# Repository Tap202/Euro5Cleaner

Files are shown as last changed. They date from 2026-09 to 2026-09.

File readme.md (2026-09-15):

# 🏍️ Yamaha MT-09 SP (Euro 5 / Euro 5+) CAN Bus Tool & Cockpit Suite







An autonomous, production-grade CAN bus diagnostic tool, real-time telemetry cockpit, and exhaust fault cleaner tailored for the **2021–2026+ Yamaha MT-09 / MT-09 SP (Euro 5 / Euro 5+ / CP3)** running on an ultra-compact **ESP32-C3 Super Mini Plus**.

Designed to live permanently under the passenger seat, it eliminates exhaust Check Engine Lights (CEL), decodes Yamaha ECU diagnostic trouble codes in real-time, logs clear history to persistent NVS flash memory, and pairs instantly with your smartphone over Bluetooth Low Energy (BLE)—with zero battery drain when parked.

---

## ⚡ Key Highlights

* 🛡️ **100% Autonomous Headless Auto-Clear**:
  * Operates completely silently in the background—**zero user interaction or phone connection required**.
  * Automatically scans ECU for trouble codes 4 seconds after ignition key-ON and clears exhaust / O2 faults (e.g. `P0036`, `P0030`) caused by aftermarket exhausts (Akrapovič, Arrow, decat headers).
  * Automatically detects engine shutdown and runs a background scan/clear cycle 3 seconds later.
* 💾 **Persistent Flash NVS Clear Logger**:
  * Automatically records every clear event to ESP32 Flash memory (`Preferences` NVS).
  * Logs boot count, uptime seconds, trigger source (`BOOT_AUTO`, `POST_RIDE`, `BLE_MANUAL`), codes cleared, and execution status.
  * Survives battery disconnections and reboots; retrievable at any time over BLE or Serial CLI.
* 🔒 **Hardware-Enforced Engine-OFF Safety Interlock**:
  * Mode 04 clear frames are strictly locked out whenever the engine is running or RPM > 0.
* 📱 **Bluetooth Low Energy (BLE 5.0) GATT Interface**:
  * Connects directly to smartphones with zero Wi-Fi network switching or internet interruption.
  * Hosted live on **GitHub Pages** (no file download needed): [**https://tap202.github.io/Euro5Cleaner/**](https://tap202.github.io/Euro5Cleaner/).
  * Works on **iOS (iPhone/iPad)** via **Bluefy** or **nRF Connect**, and on **Android/PC/Mac** via **Google Chrome** or **Edge**.
* 🌙 **Ultra-Low Power Deep Sleep (< 15 µA)**:
  * Automatically enters deep sleep after 60 seconds of CAN silence and BLE disconnection.
  * Instant hardware wakeup via GPIO 3 (`CAN_RX`) on the first dominant start-of-frame bit when the ignition key is turned ON.
  * Safe for months of parking without draining the motorcycle battery.

---

## 📱 Mobile BLE Cockpit & iOS Access Guide

### 🌐 Hosted Online via GitHub Pages (Zero Downloads Required)

You do **not** need to manually download or transfer HTML files to your phone. The BLE Cockpit is hosted for free on GitHub Pages over secure HTTPS:

👉 [**https://tap202.github.io/Euro5Cleaner/**](https://tap202.github.io/Euro5Cleaner/)

---

### 🍏 Accessing on iOS (iPhone / iPad)

> [!IMPORTANT]
> **Why Safari doesn't connect:** Apple's WebKit engine in standard Safari and Chrome for iOS intentionally does **not** support the Web Bluetooth API (`navigator.bluetooth`). 

You have two simple, free ways to use it on iOS:

#### Option A: Free Web BLE Browser (Recommended — Full Visual Dashboard)
1. Install **[Bluefy – Web BLE Browser](https://apps.apple.com/app/bluefy-web-ble-browser/id1492822055)** (Free on the iOS App Store).
2. Open Bluefy and navigate to:
   ```
   https://tap202.github.io/Euro5Cleaner/
   ```
3. Tap **Connect BLE** $\to$ select **`MT09-Cleaner`**.
4. *(Optional)* Tap the **Share / Action** icon in Bluefy and choose **"Add to Home Screen"** to turn it into a full-screen, standalone app on your iPhone!

#### Option B: Generic BLE GATT App (nRF Connect)
1. Install **[nRF Connect for Mobile](https://apps.apple.com/app/nrf-connect-for-mobile/id1054362403)** (Free on the iOS App Store).
2. Scan and connect to **`MT09-Cleaner`** (Service UUID `000018F0-0000-1000-8000-00805F9B34FB`).
3. Tap the Download / Notify icon on:
   * **`18F1` (Status)**: Live JSON string with ECU state and engine status.
   * **`18F2` (DTCs)**: Live trouble codes and descriptions.
   * **`18F4` (Logs)**: NVS flash clear history entries.
4. Write UTF-8 text commands to **`18F3` (Command)**:
   * `SCAN` : Query ECU for confirmed & pending trouble codes.
   * `CLEAR`: Safely clear codes and reset Check Engine Light.
   * `LOGS` : Refresh stored NVS history.
   * `ERASE_LOGS`: Wipe flash history.

---

### 🤖 Accessing on Android, Windows, Mac & Linux

Simply open [**https://tap202.github.io/Euro5Cleaner/**](https://tap202.github.io/Euro5Cleaner/) directly in **Google Chrome** or **Microsoft Edge**:
1. Click **Connect BLE** $\to$ select **`MT09-Cleaner`** in the pairing dialog.
2. The cockpit will automatically subscribe to notifications and display real-time statuses and logs.

---

## 🔌 Hardware Setup & Pinout

### 1. ESP32-C3 Super Mini to 3.3V CAN Transceiver (SN65HVD230)

> [!IMPORTANT]
> Always use a **3.3V CAN transceiver** such as the **SN65HVD230** or **VP230**. Do **not** connect a 5V transceiver (e.g. MCP2551 / TJA1050) directly to the ESP32 GPIOs without logic level shifters.

| ESP32-C3 Super Mini Pin | SN65HVD230 Transceiver | Description |
| :--- | :--- | :--- |
| `3V3` | `3V3` (VCC) | 3.3V Logic Supply |
| `GND` | `GND` | System Ground |
| `GPIO 21` | `TX` / `TXD` | TWAI / CAN Transmit |
| `GPIO 3` | `RX` / `RXD` | TWAI / CAN Receive (RTC GPIO Wakeup Pin) |
| `GPIO 8` | *(Onboard LED)* | Active-LOW CAN packet activity indicator |

---

### 2. Yamaha Euro 5 Diagnostic Connector (ISO 19689 Red 6-Pin)

Located underneath the passenger seat of 2021+ Yamaha MT-09 / MT-09 SP models:

```
        [ Retention Clip Top ]
      +------------------------+
      |  [1]     [2]      [3]  |
      |  [4]     [5]      [6]  |
      +------------------------+
```

| Pin # | Wire Color (Typical) | Function | Connection |
| :---: | :--- | :--- | :--- |
| **1** | Red / White | **+12V Battery** (Constant) | Optional 12V-to-5V step-down for deep sleep |
| **2** | Black | **Ground (GND)** | Connect to ESP32 & Transceiver `GND` |
| **3** | Brown / Red | **+12V Switched** (Ignition ON) | Powers on with ignition key |
| **4** | White / Black | **CAN High (CAN-H)** | Connect to Transceiver `CANH` |
| **5** | White / Blue | **CAN Low (CAN-L)** | Connect to Transceiver `CANL` |
| **6** | Yellow | K-Line (Diagnostic) | *Unused for CAN* |

> [!NOTE]
> **Termination Resistor Notice:** The motorcycle factory harness already includes internal 120Ω bus termination. If your SN65HVD230 breakout includes an onboard 120Ω resistor (marked `R2` or `120R`), it can be desoldered or left in place if total bus resistance remains above 40Ω.

---

## 🌙 Ultra-Low Power Deep Sleep & CAN RX Wakeup

The ESP32-C3 consumes approximately **5–15 µA** in deep sleep, preventing motorcycle battery drain during long storage:

1. **Auto-Sleep:** If no CAN traffic is detected for 60 seconds (ignition key switched OFF) and no BLE clients are connected, the firmware stops TWAI and BLE and enters Deep Sleep:
   ```cpp
   esp_deep_sleep_enable_gpio_wakeup(1ULL << CAN_RX_PIN, ESP_GPIO_WAKEUP_GPIO_LOW);
   esp_deep_sleep_start();
   ```
2. **Instant Dominant Wakeup:** When the motorcycle key is turned ON, the first CAN Start-of-Frame (SOF) bit pulls `CAN_RX` (GPIO 3) dominant (LOW), instantly waking the MCU in milliseconds.
3. **Headless Execution:** Upon waking, the firmware automatically runs its 4-second boot scan and clears pending exhaust codes without rider intervention.

---

## 🚀 Quickstart & Installation

### 1. Build & Flash Firmware via PlatformIO

1. Clone repository:
   ```bash
   git clone https://github.com/Tap202/Euro5Cleaner.git
   cd Euro5Cleaner
   ```
2. Connect your ESP32-C3 Super Mini via USB-C.
3. Compile and flash firmware:
   ```bash
   pio run -t upload
   ```
4. Open the Serial Monitor (115200 baud):
   ```bash
   pio device monitor -b 115200
   ```

---

## ⌨️ USB CDC Serial CLI Menu

Type any key into the Serial Monitor at **115200 baud** to interact directly with the CAN controller:

| Key | Function | Description |
| :---: | :--- | :--- |
| `?` or `h` | **Help Menu** | Prints interactive command reference. |
| `r` | **Scan DTCs** | Queries active & pending fault codes (Mode 03/07) and decodes plain-English text. |
| `k` | **Clear DTCs** | Safely transmits Mode 04 clear command to reset Check Engine Light (engine-off only). |
| `l` | **List Logs** | Displays table of persistent NVS clear events recorded in flash memory. |
| `e` | **Erase Logs** | Wipes stored clear history from NVS flash memory. |
| `a` | **Auto-Cleaner** | Toggles autonomous background auto-cleaning on/off. |
| `z` | **Deep Sleep** | Immediately puts ESP32 into ultra-low power deep sleep (wakes on CAN RX). |

---

## 🔬 Reverse-Engineered Yamaha MT-09 CAN Architecture

| CAN ID | Frequency | Description & Reverse-Engineered Payloads |
| :---: | :---: | :--- |
| **`0x751`** | 20 Hz | **Engine Running State**: Byte 7 == `0x04` indicates engine running; `0x00` engine stopped. |
| **`0x27C`** | 1,000 Hz | **Yamaha 6-Axis IMU**: Bytes 0–1 form a signed 16-bit big-endian integer representing roll/lean angle in 0.1° resolution. Muted on USB stream to prevent flooding. |
| **`0x7DF`** | Broadcast | **OBD-II Functional Request**: Transmits Mode 01 PID queries, Mode 03/07 DTC reads, and Mode 04 clears. |
| **`0x7E8`** | Response | **Engine ECU Diagnostic Response**: Responds with live powertrain PIDs and diagnostic trouble codes. |

---

## 🛡️ Safety Architecture

1. **Hardware-Enforced Engine-OFF Lockout:**
   Every Mode 04 clear request—whether triggered autonomously in the background, via the web dashboard, or through the USB CLI—passes through a strict safety interlock:
   ```cpp
   if (engineRunning || currentRpm > 0) {
       return false; // REJECTED: Never clear while engine is running
   }
   ```
2. **Listen-Only Safety Mode:**
   The CAN controller can be switched to `TWAI_MODE_LISTEN_ONLY` on the fly, guaranteeing zero dominant bus driving, zero ACK generation, and zero interference with ABS, IMU, or throttle-by-wire communications.

---

## 📄 License

This project is licensed under the **MIT License** — see the [LICENSE](LICENSE) file for details.

*Disclaimer: This project is an independent open-source development and is not affiliated with, endorsed by, or associated with Yamaha Motor Corporation. Always operate motorcycles safely and comply with local road vehicle emissions and safety regulations.*

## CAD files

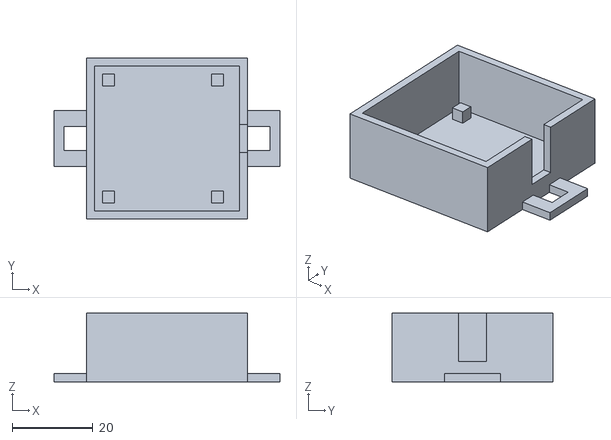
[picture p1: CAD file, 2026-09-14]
enclosure/mt09_case_base.stl
56.0 x 40.0 x 17.0

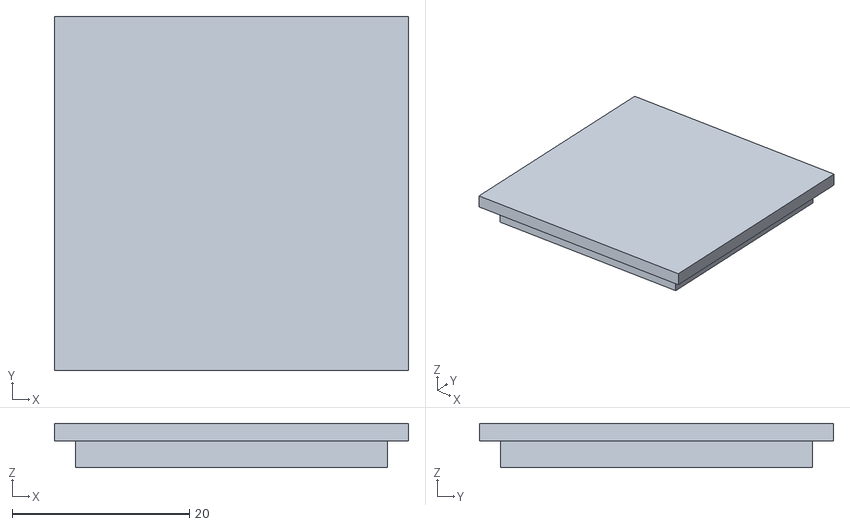
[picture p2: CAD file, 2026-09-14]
enclosure/mt09_case_lid.stl
40.0 x 40.0 x 5.00

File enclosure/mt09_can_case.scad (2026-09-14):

// =============================================================================
// 🏍️ Yamaha MT-09 SP (Euro 5+) CAN Tool - 3D Printable Weatherproof Enclosure
// Compatible with: OpenSCAD, PrusaSlicer, Bambu Studio, Cura, OrcaSlicer
// Hardware: ESP32-C3 Super Mini Plus + SN65HVD230 CAN Transceiver Module
// =============================================================================

$fn = 60; // High smoothness for curves and fillets

// --- Module & Component Dimensions (mm) ---
esp_length     = 23.5;
esp_width      = 18.5;
esp_height     = 6.0;

can_length     = 28.5;
can_width      = 12.0;
can_height     = 12.5;

wall_thickness = 2.0;
floor_thickness= 2.0;
tolerance      = 0.35; // FDM 3D printing clearance

// --- Interior Enclosure Dimensions ---
inner_length   = max(esp_length, can_length) + 6.0; // 34.5 mm
inner_width    = esp_width + can_width + 4.0;       // 34.5 mm
inner_height   = max(esp_height, can_height) + 2.5; // 15.0 mm

outer_length   = inner_length + 2 * wall_thickness;
outer_width    = inner_width + 2 * wall_thickness;
outer_height   = inner_height + floor_thickness;

// --- Cable & Zip-Tie Dimensions ---
cable_radius   = 3.2; // Slot for 4-core/6-core automotive CAN cable
ziptie_width   = 4.5;
ziptie_thick   = 2.2;

// =============================================================================
// RENDER SELECTOR (Set what you want to render/export to STL)
// =============================================================================
part_to_render = "both"; // Options: "base", "lid", "both"

if (part_to_render == "base" || part_to_render == "both") {
    case_base();
}

if (part_to_render == "lid" || part_to_render == "both") {
    // Offset lid next to base for easy 1-click plate printing
    translate([outer_length + 12, 0, 0])
        case_lid();
}

// =============================================================================
// CASE BASE (Main compartment with PCB cradles & mounting tabs)
// =============================================================================
module case_base() {
    difference() {
        union() {
            // Main rounded outer block
            rounded_cube([outer_length, outer_width, outer_height], r=3.0);

            // Subframe Zip-Tie Mounting Tabs (Left & Right)
            translate([-8, (outer_width - 14)/2, 0])
                mounting_tab();
            translate([outer_length, (outer_width - 14)/2, 0])
                mounting_tab();
        }

        // Hollow interior pocket
        translate([wall_thickness, wall_thickness, floor_thickness])
            rounded_cube([inner_length, inner_width, inner_height + 2], r=1.5);

        // Automotive Cable Entry Slot with Strain Relief Collar
        translate([outer_length - wall_thickness - 1, outer_width/2, outer_height - cable_radius])
            rotate([0, 90, 0])
                cylinder(r=cable_radius, h=wall_thickness + 2, center=false);

        // Snap-fit retention detents for the lid
        translate([wall_thickness + 6, wall_thickness - 0.4, outer_height - 2.5])
            sphere(r=0.9);
        translate([outer_length - wall_thickness - 6, wall_thickness - 0.4, outer_height - 2.5])
            sphere(r=0.9);
        translate([wall_thickness + 6, outer_width - wall_thickness + 0.4, outer_height - 2.5])
            sphere(r=0.9);
        translate([outer_length - wall_thickness - 6, outer_width - wall_thickness + 0.4, outer_height - 2.5])
            sphere(r=0.9);
    }

    // Internal PCB Separation & Cradle Wall
    translate([wall_thickness + esp_length + 2, wall_thickness, floor_thickness])
        cube([1.8, inner_width, 6.0]);

    // ESP32-C3 PCB support standoffs
    translate([wall_thickness + 2, wall_thickness + 2, floor_thickness])
        cube([3, 3, 2.5]);
    translate([wall_thickness + esp_length - 4, wall_thickness + 2, floor_thickness])
        cube([3, 3, 2.5]);
    translate([wall_thickness + 2, wall_thickness + esp_width - 4, floor_thickness])
        cube([3, 3, 2.5]);
    translate([wall_thickness + esp_length - 4, wall_thickness + esp_width - 4, floor_thickness])
        cube([3, 3, 2.5]);
}

// =============================================================================
// CASE LID (Snap-fit with embossed MT-09 SP branding & LED light pipe)
// =============================================================================
module case_lid() {
    lid_thickness = 2.0;
    rim_depth     = 3.2;

    union() {
        difference() {
            // Main outer lid plate
            rounded_cube([outer_length, outer_width, lid_thickness], r=3.0);

            // Embossed Logo / Text ("MT-09 SP")
            translate([outer_length/2, outer_width/2 + 3, lid_thickness - 0.6])
                linear_extrude(height = 1.0)
                    text("MT-09 SP", size=5.2, font="Arial:style=Bold", halign="center", valign="center");

            // Subtitle ("CAN TOOL")
            translate([outer_length/2, outer_width/2 - 5, lid_thickness - 0.6])
                linear_extrude(height = 1.0)
                    text("CAN TOOL", size=3.2, font="Arial:style=Bold", halign="center", valign="center");

            // LED Inspection Window / Light-pipe hole for GPIO 8 User LED
            translate([wall_thickness + 12, wall_thickness + 9, -1])
                cylinder(r=1.2, h=lid_thickness + 2);
        }

        // Inner snap-fit rim that inserts securely into base
        translate([wall_thickness + tolerance, wall_thickness + tolerance, -rim_depth])
            difference() {
                rounded_cube([inner_length - 2*tolerance, inner_width - 2*tolerance, rim_depth], r=1.2);
                translate([1.6, 1.6, -0.5])
                    cube([inner_length - 2*tolerance - 3.2, inner_width - 2*tolerance - 3.2, rim_depth + 1]);
            }

        // Snap beads matching base detents
        translate([wall_thickness + 6, wall_thickness + tolerance - 0.1, -2.0])
            sphere(r=0.8);
        translate([outer_length - wall_thickness - 6, wall_thickness + tolerance - 0.1, -2.0])
            sphere(r=0.8);
        translate([wall_thickness + 6, outer_width - wall_thickness - tolerance + 0.1, -2.0])
            sphere(r=0.8);
        translate([outer_length - wall_thickness - 6, outer_width - wall_thickness - tolerance + 0.1, -2.0])
            sphere(r=0.8);
    }
}

// =============================================================================
// HELPER MODULES (Mounting Tabs & Rounded Cubes)
// =============================================================================
module mounting_tab() {
    difference() {
        rounded_cube([8, 14, floor_thickness], r=2.0);
        // Zip-tie slot
        translate([2.2, (14 - ziptie_width)/2, -1])
            cube([ziptie_thick, ziptie_width, floor_thickness + 2]);
    }
}

module rounded_cube(size, r=2.0) {
    x = size[0];
    y = size[1];
    z = size[2];
    hull() {
        translate([r, r, 0]) cylinder(r=r, h=z);
        translate([x-r, r, 0]) cylinder(r=r, h=z);
        translate([r, y-r, 0]) cylinder(r=r, h=z);
        translate([x-r, y-r, 0]) cylinder(r=r, h=z);
    }
}

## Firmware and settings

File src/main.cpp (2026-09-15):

/**
 * =============================================================================
 * 🏍️ Yamaha MT-09 SP Euro 5+ Autonomous DTC Cleaner & BLE Suite
 * Platform: ESP32-C3 Super Mini Plus (RISC-V 160MHz, Native USB CDC, BLE 5.0)
 * =============================================================================
 * 
 * Features:
 *  - 100% Autonomous Headless DTC Auto-Scan & Auto-Clear (Euro 5+ TWAI @ 500 kbps)
 *  - Hardware-Enforced Engine-OFF Safety Interlock (Refuses clear if engine runs)
 *  - Persistent NVS Clear Logger (Records last 25 clear events to Flash memory)
 *  - Bluetooth Low Energy (BLE) GATT Interface:
 *      - Read active & pending ECU fault codes with plain-English definitions
 *      - Force manual scan or clear over phone (nRF Connect or Web Bluetooth)
 *      - Download persistent clear history logs
 *  - Non-blocking USB CDC Serial CLI (Zero watchdog hangs if terminal is closed)
 *  - Ultra-Low Power Deep Sleep (< 15 µA) with instant CAN RX SOF bit wakeup
 * =============================================================================
 */

#include <Arduino.h>
#include <Preferences.h>
#include <BLEDevice.h>
#include <BLEServer.h>
#include <BLEUtils.h>
#include <BLE2902.h>
#include "driver/twai.h"
#include "esp_sleep.h"

// =============================================================================
// HARDWARE PIN DEFINITIONS (ESP32-C3 Super Mini Plus)
// =============================================================================
#define CAN_TX_PIN         GPIO_NUM_21
#define CAN_RX_PIN         GPIO_NUM_3

// Onboard User LED on ESP32-C3 Super Mini is GPIO 8 (Active LOW)
#define ONBOARD_LED_PIN    8
#define LED_ACTIVE_LOW     true

// =============================================================================
// BLE SERVICE & CHARACTERISTIC UUIDs
// =============================================================================
#define SERVICE_UUID           "000018F0-0000-1000-8000-00805F9B34FB"
#define CHAR_STATUS_UUID       "000018F1-0000-1000-8000-00805F9B34FB" // Read / Notify
#define CHAR_DTCS_UUID         "000018F2-0000-1000-8000-00805F9B34FB" // Read / Notify
#define CHAR_COMMAND_UUID      "000018F3-0000-1000-8000-00805F9B34FB" // Write
#define CHAR_LOGS_UUID         "000018F4-0000-1000-8000-00805F9B34FB" // Read / Notify

BLEServer* pServer = nullptr;
BLECharacteristic* pCharStatus = nullptr;
BLECharacteristic* pCharDtcs = nullptr;
BLECharacteristic* pCharCommand = nullptr;
BLECharacteristic* pCharLogs = nullptr;

bool bleClientConnected = false;
bool oldBleClientConnected = false;

// =============================================================================
// PERSISTENT NVS STORAGE & LOGGING
// =============================================================================
Preferences prefs;
uint32_t totalClears = 0;
uint32_t bootCount = 0;
String lastClearedCode = "None";

#define MAX_CLEAR_LOGS 25
struct ClearLogEntry {
    uint32_t id;
    uint32_t boot;
    uint32_t uptimeSec;
    char trigger[16];   // "BOOT_AUTO", "POST_RIDE", "BLE_MANUAL", "CLI_MANUAL"
    char codes[32];     // e.g. "P0036, P0030"
    char result[16];    // "CLEARED_OK", "NO_CODES", "REFUSED_RUN"
};

ClearLogEntry clearLogs[MAX_CLEAR_LOGS];
uint8_t clearLogCount = 0;
uint8_t clearLogHead = 0;

// =============================================================================
// SYSTEM & CAN STATE
// =============================================================================
volatile uint16_t currentRpm = 0;
volatile bool     engineRunning = false;
volatile uint32_t totalFramesRx = 0;
volatile uint32_t busErrorCount = 0;
volatile bool     ecuDiagnosticResponseReceived = false;
volatile bool     clearAcknowledged = false;
unsigned long     lastCanRxMs = 0;

inline bool isEcuOnline() {
    return (lastCanRxMs > 0) && (millis() - lastCanRxMs < 3500);
}

bool twaiRunning = false;
bool twaiInstalled = false;
bool autoCleanEnabled = true;
bool bootAutoCleanDone = false;
unsigned long bootAutoCleanDueMs = 0;
unsigned long lastAutoScanMs = 0;
unsigned long lastAutoClearMs = 0;
const unsigned long AUTO_SCAN_INTERVAL_MS = 25000;
const unsigned long AUTO_CLEAR_COOLDOWN_MS = 10000;
bool prevEngineRunning = false;
bool prevEcuOnline = false;

unsigned long ledTurnOffMs = 0;
unsigned long bootMs = 0;
const unsigned long INACTIVITY_SLEEP_TIMEOUT_MS = 60000; // 60s silence -> Deep Sleep

// =============================================================================
// DTC DATA STRUCTURES & DEFINITIONS
// =============================================================================
#define MAX_STORED_DTCS 12
struct StoredDtcItem {
    String code;
    String desc;
};

StoredDtcItem storedDtcs[MAX_STORED_DTCS];
int storedDtcCount = 0;
bool awaitingConsecutiveDtc = false;

struct KnownDtc {
    const char* code;
    const char* desc;
};

const KnownDtc KNOWN_DTCS[] = {
    { "P0030", "HO2S Heater Circuit (Bank 1 Sensor 1)" },
    { "P0031", "HO2S Heater Low (Bank 1 Sensor 1)" },
    { "P0032", "HO2S Heater High (Bank 1 Sensor 1)" },
    { "P0036", "HO2S Heater Circuit (Bank 1 Sensor 2 - Post-Cat Exhaust / Akrapovic)" },
    { "P0037", "HO2S Heater Low (Bank 1 Sensor 2 - Post-Cat Exhaust)" },
    { "P0038", "HO2S Heater High (Bank 1 Sensor 2 - Post-Cat Exhaust)" },
    { "P0053", "HO2S Heater Resistance (Bank 1 Sensor 1)" },
    { "P0054", "HO2S Heater Resistance (Bank 1 Sensor 2 - Post-Cat Exhaust)" },
    { "P0130", "O2 Sensor Circuit (Bank 1 Sensor 1)" },
    { "P0131", "O2 Sensor Circuit Low (Bank 1 Sensor 1)" },
    { "P0132", "O2 Sensor Circuit High (Bank 1 Sensor 1)" },
    { "P0134", "O2 Sensor Circuit No Activity (Bank 1 Sensor 1)" },
    { "P0135", "O2 Sensor Heater Circuit (Bank 1 Sensor 1)" },
    { "P0136", "O2 Sensor Circuit (Bank 1 Sensor 2 - Post-Cat Exhaust)" },
    { "P0137", "O2 Sensor Circuit Low (Bank 1 Sensor 2 - Post-Cat Exhaust)" },
    { "P0138", "O2 Sensor Circuit High (Bank 1 Sensor 2 - Post-Cat Exhaust)" },
    { "P0141", "O2 Sensor Heater Circuit (Bank 1 Sensor 2 - Post-Cat Exhaust)" },
    { "P0420", "Catalyst System Efficiency Below Threshold (Bank 1 - Cat Removal)" },
    { "P0443", "EVAP Canister Purge Valve Circuit" },
    { "P0444", "EVAP Canister Purge Valve Circuit Open" },
    { "P0445", "EVAP Canister Purge Valve Circuit Shorted" },
    { "P0105", "Manifold Absolute Pressure Circuit" },
    { "P0110", "Intake Air Temperature Circuit" },
    { "P0115", "Engine Coolant Temperature Circuit" },
    { "P0120", "Throttle Position Sensor / APS Circuit" },
    { "P0201", "Injector Circuit - Cylinder 1" },
    { "P0202", "Injector Circuit - Cylinder 2" },
    { "P0203", "Injector Circuit - Cylinder 3" },
    { "P0300", "Random/Multiple Cylinder Misfire" },
    { "P0335", "Crankshaft Position Sensor A Circuit" },
    { "P0500", "Vehicle Speed Sensor Malfunction" }
};

// =============================================================================
// FUNCTION DECLARATIONS
// =============================================================================
bool initTWAI();
void stopTWAI();
void enterDeepSleep();
bool sendCanFrame(uint32_t id, uint8_t len, const uint8_t* data);
void pingEcu();
void handleFrame(const twai_message_t &rxMsg);
void handleDiagnosticResponse(const twai_message_t &rxMsg);
void requestDTCs(uint8_t mode);
bool requestClearDTCs();
bool triggerScanSequence();
bool executeClearSequence(const char* triggerSource);
void pumpTwai(uint32_t waitMs);
String decodeDTC(uint8_t b1, uint8_t b2);
void addStoredDtc(const String &code, const String &desc);
void triggerLedActivity();

void loadLogsFromNvs();
void recordClearLog(const char* trigger, const char* codesStr, const char* result);
void eraseLogsFromNvs();
String buildStatusJson();
String buildDtcsJson();
String buildLogsJson();
void notifyBleStatus();
void notifyBleDtcs();
void notifyBleLogs();

void setupBLE();
void printBanner();
void printHelp();
void printLogsCli();
void executeCliCommand(String input);

// =============================================================================
// BLE SERVER CALLBACKS
// =============================================================================
class MyServerCallbacks : public BLEServerCallbacks {
    void onConnect(BLEServer* pServer) {
        bleClientConnected = true;
        digitalWrite(ONBOARD_LED_PIN, LED_ACTIVE_LOW ? LOW : HIGH);
        delay(60);
        digitalWrite(ONBOARD_LED_PIN, LED_ACTIVE_LOW ? HIGH : LOW);
    }

    void onDisconnect(BLEServer* pServer) {
        bleClientConnected = false;
        // Restart advertising so clients can reconnect
        pServer->getAdvertising()->start();
    }
};

// =============================================================================
// BLE COMMAND CALLBACKS
// =============================================================================
class CommandCallbacks : public BLECharacteristicCallbacks {
    void onWrite(BLECharacteristic *pCharacteristic) {
        std::string rxValue = pCharacteristic->getValue();
        if (rxValue.length() == 0) return;

        String cmd = String(rxValue.c_str());
        cmd.trim();
        cmd.toUpperCase();

        if (cmd == "SCAN") {
            triggerScanSequence();
            notifyBleDtcs();
            notifyBleStatus();
        } 
        else if (cmd == "CLEAR") {
            executeClearSequence("BLE_MANUAL");
            notifyBleDtcs();
            notifyBleStatus();
            notifyBleLogs();
        } 
        else if (cmd == "LOGS") {
            notifyBleLogs();
        } 
        else if (cmd == "ERASE_LOGS") {
            eraseLogsFromNvs();
            notifyBleLogs();
            notifyBleStatus();
        }
        else if (cmd == "AUTO_ON") {
            autoCleanEnabled = true;
            notifyBleStatus();
        }
        else if (cmd == "AUTO_OFF") {
            autoCleanEnabled = false;
            notifyBleStatus();
        }
    }
};

// =============================================================================
// SETUP
// =============================================================================
void setup() {
    // Initialize USB CDC Serial with NON-BLOCKING timeout (0ms)
    // Prevents watchdog hangs when USB is plugged in but Serial Monitor is closed!
    Serial.begin(115200);
    Serial.setTxTimeoutMs(0);

    // Initialize Onboard Activity LED
    pinMode(ONBOARD_LED_PIN, OUTPUT);
    for (int i = 0; i < 3; i++) {
        digitalWrite(ONBOARD_LED_PIN, LED_ACTIVE_LOW ? LOW : HIGH);
        delay(80);
        digitalWrite(ONBOARD_LED_PIN, LED_ACTIVE_LOW ? HIGH : LOW);
        delay(80);
    }

    // Optional short wait for terminal if connected
    unsigned long startWait = millis();
    while (!Serial && (millis() - startWait < 500)) {
        delay(10);
    }

    printBanner();

    // Check wakeup reason (GPIO 3 wakeup on CAN Dominant SOF bit when ignition turns ON)
    esp_sleep_wakeup_cause_t wakeupReason = esp_sleep_get_wakeup_cause();
    if (wakeupReason == ESP_SLEEP_WAKEUP_GPIO) {
        if (Serial) Serial.println("[WAKE] ⚡ ESP32 woke from Deep Sleep via CAN RX activity (Ignition ON)!\n");
    }
    lastCanRxMs = millis();

    // 1. Initialize NVS Storage & Load Logs
    prefs.begin("mt09_clean", false);
    bootCount = prefs.getUInt("boots", 0) + 1;
    prefs.putUInt("boots", bootCount);
    totalClears = prefs.getUInt("clears", 0);
    lastClearedCode = prefs.getString("last_code", "None");
    loadLogsFromNvs();

    if (Serial) {
        Serial.printf("[NVS] Boots: %u | Total Clears Logged: %u | Last Code: %s | Stored Logs: %u\n",
                      bootCount, totalClears, lastClearedCode.c_str(), clearLogCount);
    }

    // 2. Initialize Bluetooth Low Energy (BLE)
    setupBLE();

    // 3. Initialize TWAI CAN Controller at 500 kbps (Euro 5 Standard)
    if (initTWAI()) {
        if (Serial) {
            Serial.printf("[INIT] CAN Controller initialized on TX: GPIO %d, RX: GPIO %d\n", CAN_TX_PIN, CAN_RX_PIN);
            Serial.println("[INIT] Autonomous Background DTC Auto-Cleaner: ACTIVE (No user input required)\n");
        }
    } else {
        if (Serial) Serial.println("[ERROR] Failed to start CAN Controller! Check wiring.");
    }

    bootMs = millis();
    bootAutoCleanDueMs = bootMs + 4000;
}

// =============================================================================
// BLE INITIALIZATION
// =============================================================================
void setupBLE() {
    BLEDevice::init("MT09-Cleaner");
    pServer = BLEDevice::createServer();
    pServer->setCallbacks(new MyServerCallbacks());

    BLEService *pService = pServer->createService(SERVICE_UUID);

    // Status Characteristic (Read / Notify)
    pCharStatus = pService->createCharacteristic(
        CHAR_STATUS_UUID,
        BLECharacteristic::PROPERTY_READ | BLECharacteristic::PROPERTY_NOTIFY
    );
    pCharStatus->addDescriptor(new BLE2902());
    pCharStatus->setValue(buildStatusJson().c_str());

    // DTCs Characteristic (Read / Notify)
    pCharDtcs = pService->createCharacteristic(
        CHAR_DTCS_UUID,
        BLECharacteristic::PROPERTY_READ | BLECharacteristic::PROPERTY_NOTIFY
    );
    pCharDtcs->addDescriptor(new BLE2902());
    pCharDtcs->setValue(buildDtcsJson().c_str());

    // Command Characteristic (Write)
    pCharCommand = pService->createCharacteristic(
        CHAR_COMMAND_UUID,
        BLECharacteristic::PROPERTY_WRITE
    );
    pCharCommand->setCallbacks(new CommandCallbacks());

    // Logs Characteristic (Read / Notify)
    pCharLogs = pService->createCharacteristic(
        CHAR_LOGS_UUID,
        BLECharacteristic::PROPERTY_READ | BLECharacteristic::PROPERTY_NOTIFY
    );
    pCharLogs->addDescriptor(new BLE2902());
    pCharLogs->setValue(buildLogsJson().c_str());

    pService->start();

    BLEAdvertising *pAdvertising = BLEDevice::getAdvertising();
    pAdvertising->addServiceUUID(SERVICE_UUID);
    pAdvertising->setScanResponse(true);
    pAdvertising->setMinPreferred(0x06); // functions that help with iPhone connections issue
    pAdvertising->setMinPreferred(0x12);
    BLEDevice::startAdvertising();

    if (Serial) Serial.println("[BLE] Advertising started as 'MT09-Cleaner' (UUID: 18F0)\n");
}

// =============================================================================
// MAIN LOOP
// =============================================================================
void loop() {
    unsigned long now = millis();

    // 1. Service non-blocking USB CDC Serial CLI
    if (Serial && Serial.available()) {
        String input = Serial.readStringUntil('\n');
        input.trim();
        if (input.length() > 0) {
            executeCliCommand(input);
        }
    }

    // 2. Process incoming CAN messages from TWAI hardware
    if (twaiRunning) {
        twai_message_t rxMsg;
        uint8_t rxBatch = 0;
        while (twai_receive(&rxMsg, 0) == ESP_OK && rxBatch < 30) {
            handleFrame(rxMsg);
            rxBatch++;
        }

        uint32_t alertsTriggered = 0;
        if (twai_read_alerts(&alertsTriggered, 0) == ESP_OK) {
            if (alertsTriggered & TWAI_ALERT_BUS_ERROR) {
                busErrorCount++;
            }
            if (alertsTriggered & TWAI_ALERT_BUS_OFF) {
                if (Serial) Serial.println("\n[ALERT] TWAI Bus-Off detected! Initiating recovery...");
                twai_initiate_recovery();
            }
            if (alertsTriggered & TWAI_ALERT_BUS_RECOVERED) {
                if (Serial) Serial.println("\n[ALERT] TWAI Bus Recovered!");
                twai_start();
            }
        }
    }

    // Check for ECU online/offline transition
    bool currentEcuOnline = isEcuOnline();
    if (currentEcuOnline != prevEcuOnline) {
        prevEcuOnline = currentEcuOnline;
        if (Serial) Serial.printf("\n[ECU STATE] Motorcycle ECU is now: %s\n\n", currentEcuOnline ? "ONLINE (Ignition ON)" : "OFFLINE (Ignition OFF)");
        notifyBleStatus();
        notifyBleDtcs();
    }

    // 3. AUTONOMOUS BACKGROUND DTC AUTO-SCAN & AUTO-CLEAR
    if (autoCleanEnabled && twaiRunning) {
        // A. Boot auto-scan: runs ONCE 4s after Key ON, then goes silent
        if (!bootAutoCleanDone && currentEcuOnline && now >= bootAutoCleanDueMs) {
            bootAutoCleanDone = true;
            if (!engineRunning && currentRpm == 0) {
                if (Serial) Serial.println("\n[AUTO-CLEAN] 🚀 Key ON detected: Scanning ECU for trouble codes (Engine OFF)...");
                triggerScanSequence();
                if (storedDtcCount > 0) {
                    executeClearSequence("BOOT_AUTO");
                } else {
                    if (Serial) Serial.println("[AUTO-CLEAN] ✅ Boot check: System clean! 0 trouble codes found in ECU.\n");
                }
                notifyBleDtcs();
                notifyBleStatus();
                if (Serial) Serial.println("[AUTO-CLEAN] CAN transmissions stopped. Yamaha ECU diagnostic mode will exit in ~3s.\n");
            }
        }

        // B. Detect Engine Stop transition (e.g. rider turned off kill switch or finished ride)
        if (prevEngineRunning && !engineRunning && currentEcuOnline) {
            if (Serial) Serial.println("\n[AUTO-CLEAN] Engine shutdown detected. Running post-ride DTC check in 3s...");
            lastAutoScanMs = now - (AUTO_SCAN_INTERVAL_MS - 3000);
            bootAutoCleanDone = false; // Arm check for next startup
        }
        prevEngineRunning = engineRunning;
    }

    // 5. Handle Non-blocking Activity LED turn off
    if (ledTurnOffMs > 0 && now >= ledTurnOffMs) {
        digitalWrite(ONBOARD_LED_PIN, LED_ACTIVE_LOW ? HIGH : LOW);
        ledTurnOffMs = 0;
    }

    // 6. Low-Power Deep Sleep Inactivity Check
    // If no CAN traffic for 60s and no phone connected via BLE, enter deep sleep (<15 µA)
    if (twaiRunning && (now - lastCanRxMs >= INACTIVITY_SLEEP_TIMEOUT_MS)) {
        if (!bleClientConnected) {
            enterDeepSleep();
        }
    }

    delay(2);
}

// =============================================================================
// SCAN & CLEAR WORKFLOW ENGINES
// =============================================================================
void pingEcu() {
    uint8_t payload[8] = { 0x02, 0x01, 0x00, 0x55, 0x55, 0x55, 0x55, 0x55 };
    sendCanFrame(0x7DF, 8, payload);
}

bool triggerScanSequence() {
    storedDtcCount = 0;
    ecuDiagnosticResponseReceived = false;

    requestDTCs(0x03); // Confirmed DTCs
    pumpTwai(140);
    requestDTCs(0x07); // Pending DTCs
    pumpTwai(140);

    return ecuDiagnosticResponseReceived;
}

bool executeClearSequence(const char* triggerSource) {
    if (engineRunning || currentRpm > 0) {
        if (Serial) Serial.println("\n⚠️ [CLEAR REFUSED] SAFETY GUARD: Engine is RUNNING! Turn off engine to clear.\n");
        recordClearLog(triggerSource, "BLOCKED", "REFUSED_RUN");
        return false;
    }

    // Build comma-separated string of codes being cleared
    String codesStr = "";
    for (int i = 0; i < storedDtcCount; i++) {
        if (i > 0) codesStr += ", ";
        codesStr += storedDtcs[i].code;
    }
    if (codesStr.length() == 0) codesStr = "None";

    if (Serial) Serial.println("\n🧹 [CLEAR] Transmitting OBD Mode 04 clear command to ECU...");
    clearAcknowledged = false;
    bool sent = requestClearDTCs();
    if (!sent) {
        if (Serial) Serial.println("❌ [CLEAR ERROR] Failed to transmit clear frame on CAN bus.\n");
        recordClearLog(triggerSource, codesStr.c_str(), "TX_FAILED");
        return false;
    }

    // Wait up to 350ms for ECU positive acknowledgment (Mode 04 response: 0x44)
    unsigned long startWait = millis();
    while (!clearAcknowledged && (millis() - startWait < 350)) {
        pumpTwai(10);
    }

    if (clearAcknowledged) {
        lastCanRxMs = millis();
        totalClears++;
        prefs.putUInt("clears", totalClears);
        if (storedDtcCount > 0) {
            lastClearedCode = storedDtcs[0].code;
            prefs.putString("last_code", lastClearedCode);
        }
        recordClearLog(triggerSource, codesStr.c_str(), "CLEARED_OK");
        storedDtcCount = 0;
        lastAutoClearMs = millis();

        if (Serial) Serial.printf("🎉 [CLEAR CONFIRMED] ECU acknowledged Mode 04 (0x44)! Erased codes (%s). Total logged: %u\n\n", codesStr.c_str(), totalClears);
        return true;
    } else {
        if (Serial) Serial.println("⚠️ [CLEAR UNCONFIRMED] No 0x44 ACK received (ECU may be OFF).\n");
        recordClearLog(triggerSource, codesStr.c_str(), "NO_ECU_ACK");
        return false;
    }
}

// =============================================================================
// TWAI CONTROLLER MANAGEMENT & TRANSMIT
// =============================================================================
bool initTWAI() {
    if (twaiRunning) stopTWAI();

    twai_general_config_t g_config = TWAI_GENERAL_CONFIG_DEFAULT(CAN_TX_PIN, CAN_RX_PIN, TWAI_MODE_NORMAL);
    g_config.rx_queue_len = 32;
    g_config.tx_queue_len = 8;
    g_config.alerts_enabled = TWAI_ALERT_BUS_ERROR | TWAI_ALERT_BUS_OFF | TWAI_ALERT_BUS_RECOVERED;

    twai_timing_config_t t_config = TWAI_TIMING_CONFIG_500KBITS();
    twai_filter_config_t f_config = TWAI_FILTER_CONFIG_ACCEPT_ALL();

    esp_err_t err = twai_driver_install(&g_config, &t_config, &f_config);
    if (err != ESP_OK) return false;
    twaiInstalled = true;

    err = twai_start();
    if (err != ESP_OK) {
        twai_driver_uninstall();
        twaiInstalled = false;
        return false;
    }
    twaiRunning = true;
    return true;
}

void stopTWAI() {
    if (twaiRunning) {
        twai_stop();
        twaiRunning = false;
    }
    if (twaiInstalled) {
        twai_driver_uninstall();
        twaiInstalled = false;
    }
}
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

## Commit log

2026-09-05 Refactor CAN/BLE logic to prevent crashes and optimize hardware usage
    - Fix OTA memory crashes by deinitializing the BLE stack before starting Wi-Fi.
    - Make BLE RX callbacks non-blocking by offloading `bleSendLine` transmissions to the main loop via state flags.
    - Fix TWAI filter configuration by replacing the inverted hardware mask with standard ACCEPT_ALL to ensure proper software filtering.
    - Implement closed-loop OBD telemetry polling to prevent CAN bus flooding, waiting for ECU responses with a 250ms timeout failsafe.
    - Add deduplication check in NVS logging to prevent excessive flash memory wear cycles during persistent DTCs.
    [main.cpp]
2026-09-05 refactor: optimize CAN bus reliability, thread safety, and OTA workflow
    - Implement `std::atomic<bool>` for BLE flags to ensure thread safety across FreeRTOS tasks.
    - Add true hardware CAN filtering (IDs 0x7E8-0x7EF) to prevent TWAI RX queue flooding.
    - Fix ISO-TP multi-frame flow control by requesting 8-frame blocks and sending Abort (0x32) on buffer overflows.
    - Optimize NVS flash wear by saving individual DTC records via dynamic keys rather than overwriting the entire history array.
    - Remove hardcoded Wi-Fi credentials and integrate `WiFiManager` for dynamic captive portal OTA configuration.
    [main.cpp]
2026-09-05 fix: resolve narrowing conversion error in TWAI filter config
    The C++ compiler threw a `-Wnarrowing` error during build because the bit-shifted hex literals (`0x7E8 << 21`) were implicitly treated as signed integers, resulting in negative values being assigned to the unsigned `uint32_t` struct members.
    Added the `U` suffix to the hex values (`0x7E8U`, `0x007U`) and explicitly cast the operations to `uint32_t`. This ensures the bit-shifting yields proper unsigned 32-bit integers, fixing the build failure.
    [main.cpp]
2026-09-05 perf: Decouple CAN parsing from BLE and optimize ISO-TP flow
    - Introduced a FreeRTOS Queue and a dedicated `bleTxTask` to handle BLE notifications asynchronously. This removes the blocking 20ms `vTaskDelay` from the CAN RX path, preventing the TWAI driver queue from overflowing and dropping frames during heavy bus traffic.
    - Offloaded heavy string formatting (`snprintf` for telemetry) from the time-critical CAN parser into the main loop via a thread-safe `telemetryUpdated` atomic flag.
    - Updated ISO-TP Flow Control logic to request a Block Size of 0 (`fc.data[1] = 0x00`). This instructs the ECU to send all remaining consecutive frames continuously, optimizing transfer speeds and stripping un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
    [main.cpp]
2026-09-05 fix(obd): correct ISO-TP DTC offsets, RTOS queue drops, and OTA blocking
    - Refactored `processDTCs` to strictly accept a buffer starting at the first fault code, eliminating offset misalignment between single and multi-frame ISO-TP payloads.
    - Added `wm.setConfigPortalTimeout(120)` to WiFiManager to prevent infinite blocking on Core 1 if the OTA AP is abandoned, preventing Task WDT panics.
    - Increased `BLE_MSG_QUEUE_LEN` from 20 to 50 to accommodate full CSV exports.
    - Changed `bleSendLine` queue wait time from 0 to 10 ticks to apply mild RTOS backpressure instead of silently dropping data.
    - Pinned `bleTxTask` to Core 0 (PRO_CPU) via `xTaskCreatePinnedToCore` to isolate BLE execution from m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
    [main.cpp]
2026-09-05 refactor: improve memory safety, loop constraints, and flash wear
    - Added buffer bounds checking to `processDTCs` to prevent out-of-bounds reads if a corrupted CAN frame declares an artificially high code count.
    - Capped CAN message processing in the main loop to a maximum of 15 frames per tick to prevent CPU starvation and ensure BLE/RTOS tasks are smoothly serviced.
    - Implemented deferred NVS writes for DTC history. Fault codes are now cached in RAM and committed to flash memory only when engine RPM reaches 0, reducing unnecessary flash wear.
    [main.cpp]
2026-09-12 altered pin definitions
2026-09-14 feat: complete Euro 5+ suite with Wi-Fi cockpit, IMU lean angle, ride logger, deep sleep, and 3D enclosure
    [mt09_can_case.scad, mt09_case_base.stl, mt09_case_lid.stl]
2026-09-15 Update README to remove enclosure and hosting instructions

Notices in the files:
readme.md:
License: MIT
